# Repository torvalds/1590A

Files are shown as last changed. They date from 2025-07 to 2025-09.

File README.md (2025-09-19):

## Random guitar pedal board designs for 1590A enclosures

> [!NOTE]
> This repository is no longer maintained in favor for [GuitarPedal](https://github.com/torvalds/GuitarPedal).

### Electrical

These are not at all useful, but having done guitar pedal board kit
builds, I decided I should try to make something from scratch.  I don't
actually play guitar, but guitar pedal kits were fun to solder, and that
then turned into "I want to actually understand what they do"...

> [!NOTE]
> I'm not soldering wires together like some kind of animal ---
> thus PCBs designed in KiCad.
>
> And not only don't I solder wires, I like surface-mount
> components.  And not just because some newer stuff isn't
> even available in through-hole form any more.
>
> Everything is designed to be "hand-soldered" --- although
> your definition of hand-soldering may differ from mine. The
> boards are double-sided, but surface mount components are
> only on one side, typically with the other side used only
> for connectors and the like.
>
> I do these without a stencil. It's entirely doable, and I'm
> consciously limiting myself to fairly simple footprints

The design is split up into a "base board" and "effects boards", because
the 1590A is pretty tight.

The base board should work with any of the effect boards, and is purely
about the connectors and stomp switch with true bypass.

The base board does nothing to the signal (apart from the purely
physical switching of the stomp switch), and only does some very basic
reverse polarity protection and has some capacitors for the 9V power
supply.

The effects boards are random "Linus is testing things he doesn't know
anything about".

 - There's a random "Fuzz" board that I may still play around with,
   which just does some random signal clipping with a diode. I'm keeping
   that one around just as a starting point for other potential boards.

 - There's an "Octaver" board that is just a signal rectifier. I started
   out doing those with a op-amp based precision rectification circuit,
   but now it's a dual transistor discrete circuit instead.

   The rectification is objectively worse, but it's not like it made the
   sound any better, and the circuit is much more interesting.

 - There's a plain "clean boost" thing, which should be clean until the
   boosting starts to clip. Which happens pretty quickly since it's a
   pretty aggressive 25dB boost - assuming my simulation matches
   reality, which it might not do.

All of this has been tested and found lacking.  But now my simulation is
much better, and includes some real audio samples.  That didn't make any
of the circuits sound better, but once you realize that any sane modern
guitar pedals are all digital, and that this is just to learn the basics
of transistors etc, that's all good.

### Mechanicals

These are all trivial two-layer boards.  They could be single-sided with
very little routing problem, but that would only complicate things for
no gain.

It's not like I would ever want to even try to etch boards at home any
more, because while I go for "large" components, that's still very
relative.  Etching boards is messy and doing it with the precision
needed for smd is just too painful to be worth it.  See below on
components.

So just use JLCPCB or your favorite other board house.

### Components

Connectors and potentiometers are typically from Tayda Electronics, with
most of the actual common SMD components from kits or from Mouser.

For "random" SMD capacitors and resistors, get one of the kits.  I can
personally heartily recommend the Guanruixin kits from Amazon: there are
0805 and 1206 kits of both capacitors and resistors, and I love the
packaging and labeling.  Very good for organizing at a hobbyist level.

The AideTek kits are good too, but the Guanruixin ones are really
compact for those "get all the values just in case" situations.

Then just go to Mouser or Digikey and buy cut tape for the values you
use more of.  You'll run out of the common resistors in the kits, but
they are still worth having for the less usual ones and just for the
organizing.

And things that are just a bit more specialized - like the the C0G caps
in higher capacitances - you won't find in the kits.

Also, while I'm doing discrete components, I still consider "dual
diodes" etc to be discrete.  In fact I much prefer those for things like
diodes and transistors when possible (and if you want matched pairs
obviously make those a requirement - I realize some people do the manual
matching, but that's not for me).

I've picked SOT-23-6 packages over SOT-363 or SOT-563 because I find
that my limit for enjoying the soldering is at about the 1mm pin pitch.
The 0.65mm or 0.5mm pitch stuff ends up being just annoying.

The resistors are all 0805 size, and capacitors are all over the place:
smaller capacitors in the pF or nF range are 0805, bigger ones are 1206,
and I ended up with 0.1uF C0G in 0704 because it was a common cap choice
for both signal re-biasing and for op-amp bypassing, and doing 1206 was
actually taking up noticeable amounts of board space in some cases.

Electro-mechanical:

 - Tayda A-6976: 1/4" thread lock panel mount mono jack CK635008

 - Tayda A-1848 etc: ALPHA 9mm PCB-mount potentiometers

 - Tayda A-4191: ALPHA 3PDT latching stomp switch.

 - Tayda A-3670 etc: 1M series mini toggle switches and the sub-mini 2M
   series for the side switch.

 - Wuerth 694106301002 9V DC power jack

 - Hammond 1590A enclosure. There are drill patterns that work here:
   ["Tayda drill patterns"](/Tayda/Enclosure-drill-holes)

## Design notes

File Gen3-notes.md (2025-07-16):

Lessons learnt from Gen 1/2:

### Power rails

I started out with various base boards that generally generated negative
power rails, because it felt like the RightThing(tm).  Then Gen2 ended
up just using a virtual ground at 4.5V anyway because anything else was
unnecessarily complex.

But that caused issues too, and when I went all old-school and decided
that even op-amps were too fancy, and I actually wanted to regress to
just entirely discrete components, even the 4.5V virtual ground was just
a distraction.

The simplest discrete boards just don't need it or want it, and even
when they do a reference voltage they don't necessarily pick the
mid-point of the supply.

So the gen3 base board is entirely passive, with no signal buffering or
any re-biasing.  So all the base board does is the stomp switch bypass,
and some very basic power supply sanity (a high-side P-MOSFET for
reverse polarity protection and some capacitors for power supply
stability).

### 1590A enclosure fit

This is a solved problem.  Gen1 was borderline and was playing with
power connectors etc, gen2 tweaked some of the positioning, but I think
gen3 is "done".

The internal inter-board connector did change in gen3, because it's now
simpler with a minimal 4-pin header (just GND / 9V / In / Out) and more
out of the way.  But that didn't affect the enclosure, just the board
pairings.

### Circuits

The lesson from Gen 1/2 has mostly been that I don't actually care about
how things sound, and what I like is the tinkering, and trying to
(still) understand the circuits.

So laying out and soldering the boards is still fun, but using op-amps
to buffer a signal has become "just do it with a transistor".

Because while op-amps are clearly simpler and better to technology to
use, they kind of miss the point of "let's understand what's going on"
by just adding that whole abstraction layer.

So the circuits have regressed to being even simpler and more pointless.

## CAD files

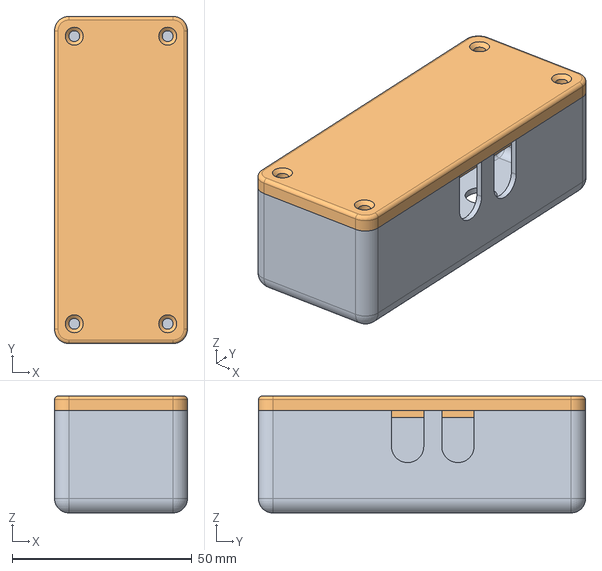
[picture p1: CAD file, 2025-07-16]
Models/enclosure_1590A.FCStd
37.0 x 91.0 x 32.5 mm

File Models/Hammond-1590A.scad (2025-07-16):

// Hammond 1590A enclosure
// Three-pot version with stomp switch and LED
$fn = 100;

// Knob definitions
no_knob = [];
one_knob = [[0,24]];
three_knob = [[-8, 32], [8, 32], [0,16]];
four_knob = [[-8, 32], [8, 32], [-8,16], [8,16]];

// Jack definitions
normal = [[0,-18], [-40,-4]];
splitter = [[0,-18], [-40,-4], [-40,10]];
joiner = [[0,-18], [-40,-4], [0,10]];

// Switch definitions
no_switch = [];
one_switch = [[12,-34]];

// This sets up the configuration
knob_positions = one_knob;
jack_positions = splitter;
switch_positions = no_switch;

screw_positions = [[-14.25,-41.3], [-14.25,41.3], [14.25,-41.3], [14.25,41.3]];

// Do the nice rounded corners and a slight
// taper on the exterior. We'll cut the bottom
// off as part of the cutouts, so don't worry
// about the part going under the XY plane
//
// Bottom: 40.0mm wide, 94.5mm tall
// Top:    38.5mm wide, 92.6mm tall
// 28.5mm high
module exterior()
{
    minkowski() {
        linear_extrude(height = 23.5, scale=[0.9625,0.98]) {
            square([30, 84.5], center=true);
        }
        sphere(r=5);
    }
}

// Same square as the exterior, but the minkowski circle
// is 3mm vs the 5mm sphere.  So basically 2mm walls
module bottom()
{
    minkowski() {
        square([30, 84.5], center=true);
        circle(r=3);
    }
}

// Screw pillar base
module screw_pillar_2d()
{
    for (i = [-1:2:1]) {
        for (j = [-1:2:1]) {
            translate([i*14.25, j*41.3]) {
                hull() {
                    circle(d=5);
                    translate([i*2.5, 0])
                        square(5, center=true);
                    translate([0, j*2.5])
                        square(5, center=true);
                }
            }
        }
    }
}

module screw_holes()
{
    for (pos = screw_positions)
        translate(pos) {
            cylinder(h=14, d=2.9);
            cylinder(h=5, r1=4, r2=1.5);
        }
}

// The bottom extruded up, but with the
// screw pillars removed
module interior_space()
{
    difference() {
        linear_extrude(height=26.5, scale=0.98)
            bottom();
        linear_extrude(height=26.5)
            screw_pillar_2d();
    }
}

// This is the interior that gets removed
module interior()
{
    linear_extrude(height=4)
        bottom();

    interior_space();
    screw_holes();
}

module knob_cutout(pos)
{
    translate(pos)
        cylinder(h=40, d=7.7);
}

module knobs()
{
    for (pos = knob_positions)
        knob_cutout(pos);
}

module jack_cutout(pos)
{
    translate(pos) {
        rotate(90, [0,1,0]) {
            translate([-10,0])
                cylinder(h=40, d=9);
            translate([0,0,20])
                cube([20,9,40], center=true);
        }
    }
}

module audio_jacks()
{
    for (pos = jack_positions)
        jack_cutout(pos);
}

// 9.5mm wide, 14mm high
module dc_jack()
{
    translate([0,45])
        cube([9.5,30,28], center=true);
}

// Stomp switch and hole for LED
module stomp_switch()
{
    translate([0,-34])
        cylinder(h=40, d=13);
    translate([-12,-34])
        cylinder(h=40, d=6);
    for (pos = switch_positions)
        translate(pos)
            cylinder(h=40, d=6);
}

module cut()
{
    interior();
    knobs();
    audio_jacks();
    dc_jack();
    stomp_switch();

    translate([0,0,-5])
        cube([100,100,10], center=true);
}


// Main body
difference() {
    exterior();
    cut();
}

// The lid is the rounded exterior, we're just cutting off
// the top instead of the bottom and then working on that.
module lid_cut()
{
    translate([0,0,20])
        cube([50,100,40], center=true);
    translate([0,0,-2.5])
        linear_extrude(height=3)
            bottom();
}

module lid()
{
    difference() {
        exterior();
        lid_cut();
    }

    // Add corner screw pillars
    // Reinforce around the screw heads
    translate([0,0,-2.5]) {
        linear_extrude(height=5) {
            intersection() {
                screw_pillar_2d();
                bottom();
            }
        }

        for (pos = screw_positions)
            translate(pos)
                cylinder(h=5,d1=10,d2=5);
    }
}

translate([60, 0, 5]) {
    difference() {
        lid();
        translate([0,0,-5])
            screw_holes();
    }
}

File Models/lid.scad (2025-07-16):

$fn=50;

// Knob definitions
no_knob = [];
one_knob = [[0,24]];
three_knob = [[-8, 32], [8, 32], [0,16]];
four_knob = [[-8, 32], [8, 32], [-8,16], [8,16]];

// Jack definitions
normal = [[0,-18], [-40,-4]];
splitter = [[0,-18], [-40,-4], [-40,10]];
joiner = [[0,-18], [-40,-4], [0,10]];

// Switch definitions
no_switch = [];
one_switch = [[12,-34]];

// This sets up the configuration
knob_positions = three_knob;
jack_positions = normal;
switch_positions = no_switch;

screw_positions = [[-15,-42.25], [-15,42.25], [15,-42.25], [15,42.25]];

module cutouts()
{
	translate([20,-25])
		square([7,5], true);
	translate([-20,-25])
		square([7,5], true);
	translate([20,39])
		square([7,5], true);
	translate([-20,39])
		square([7,5], true);
}

module exterior()
{
	difference() {
		minkowski() {
		        square([30, 84.5], center=true);
        		circle(r=5);
		};
		cutouts();
	}
}

// Same square as the exterior, but the minkowski circle
// is 3mm vs the 5mm sphere.  So basically 2mm walls
module interior()
{
	minkowski() {
		square([30, 84.5], center=true);
		circle(r=3);
	}
}

module bottom()
{
	difference() {
		linear_extrude(height=6)
			exterior();
		translate([0,0,2])
			linear_extrude(height=5)
				interior();
	}
	translate([-10,20])
		cylinder(h=3.8, r=2);
	translate([10,20])
		cylinder(h=3.8, r=2);
	// Walls
	translate([18,20])
		linear_extrude(height=11.5)
			square([4,20],true);
	translate([-18,20])
		linear_extrude(height=11.5)
			square([4,20],true);
	translate([18,-33])
		linear_extrude(height=11.5)
			square([4,10],true);
	translate([-18,-33])
		linear_extrude(height=11.5)
			square([4,10],true);		
	translate([0,-(84.5/2 + 5 - 2)])
		linear_extrude(height=11.5)
			square([20,4],true);
}

module holes()
{
	translate([0,-34])
		cube([21,18,10], true);
	translate([12,-34,-5])
		cylinder(h=40, d=10);
	for (pos = knob_positions) {
		translate(pos)
			translate([0,-2,0])
				cube([11,13,10], true);
	}
}

module top()
{
	difference() {
		bottom();
		holes();
	}
	translate([-10,-20])
		cylinder(h=3.8, r=2);
	translate([10,-20])
		cylinder(h=3.8, r=2);
}

bottom();
translate([-10,2])
	cylinder(h=3.8, r=2);
translate([10,2])
	cylinder(h=3.8, r=2);
translate([45,0])
	top();
for (pos = screw_positions)
	translate(pos)
		cylinder(h=21, d=6);

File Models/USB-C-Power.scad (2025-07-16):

// Simple enclosure for the USB-C power board
//
// Board dimensions:
//    80 x 30mm with 5mm corner radius
//
// DC jacks centered on front panel at X -30, -10, +10, and +30mm
// USB C receptable on back panel at +20mm
//
// board: 1.6mm thick with 2mm high components (3.4mm if choke on back)
// so let's say 5mm undercut
//
// Top of board: DC jacks 11mm high, but caps up to 12.5mm, go for
// 15mm space above: 20mm total cavity height.

$fn = 100;

// Corner locations
corners = [[-40,-15],[-40,15],[40,-15],[40,15]];

// 3mm hole board locations
holes = [[-35,+10], [+35,+10], [-20,-7.5], [+20,-7.5]];

module board_2d()
{
    minkowski() {
        square([80,30], center=true);
        circle(r=1);
    }
}

// 2mm walls around the board cutout
module exterior()
{
    minkowski() {
        linear_extrude(height=20)
            board_2d();
        sphere(r=2);
    }
}

// 9mm wide, 11mm high with 0.5mm for slop
// Translate up 10.75mm: 5mm undercut + 5.75mm for half the height
module dc_jacks()
{
    for (x = [-30:20:30])
        translate([x,-15,10.75])
            cube([9.5,15,11.5], center=true);
}

// USB-C cable cutout:
//    Plug end dimensions:   8.35mm x 2.56mm
//    Cable end dimensions: 12.35mm x 6.5mm max
// So basically cable is 2mm on each side of the plug.
//
// Centered at 5mm undercut + 1.6mm up from the board
module usbc_jack()
{
    translate([20,10,6.6])
        minkowski() {
            cube([8.35,20,2.56], center=true);
            sphere(d=3.8);
        }
}

// The capacitors in between the DC jacks can be high
// and might need a cutout because of how we support
// the DC jacks above.
module capacitors()
{
    translate([0,-4,5])
        cylinder(h=12.5,d=8);
    translate([0,-11,5])
        cylinder(h=12.5,d=8);
}

module mounting_pin(loc)
{
    translate(loc) {
        cylinder(h=3.4, d1=12, d2=8);
        translate([0,0,5])
            cylinder(h=15, d=8);
    }
}

module screw()
{
    // 0: 3 5: 2.9 10: 2.8 15:2.7
    cylinder(h=15, d1=3, d2=2.7);
    translate([0,0,-2])
        cylinder(h=7, d1=8, d2=3);
}

module corner_clips()
{
    translate([0,0,5])
    for (loc = corners)
        translate(loc)
            cylinder(h=15,r=3);
    translate([0,0,2])
        linear_extrude(height=3)
            intersection() {
                for (loc = corners)
                    translate(loc)
                        circle(2);
                board_2d();
            }
}

module cutout()
{
    // Extrude the board cutout, but not above the DC jacks.
    // We'll separately cut out the DC jacks to keep them
    // captured for easy soldering inserted in the box.
    // Also, we don't cut out the mounting pins around holes.
    difference() {
        linear_extrude(height=20)
            board_2d();
        translate([0,-15,20])
            cube([80,15,10], center=true);
	for (loc = holes)
            mounting_pin(loc);
    }
    translate([0,0,3.4])
        linear_extrude(height=1.6)
            board_2d();
    dc_jacks();
    usbc_jack();
    capacitors();

    // Add screw holes
    for (pos = holes)
        translate(pos)
            screw();
}

module box()
{
    difference() {
        exterior();
        cutout();
    }
}

// Now do it twice for the upper and lower parts, cut off at 5mm
// The box itself
difference() {
    box();
    cube([100,100,10],center=true);
}

corner_clips();

// Lid
translate([0, -45, 0]) {
    difference() {
        box();
        translate([0,0,35])
            cube([100,100,60],center=true);
    }
}

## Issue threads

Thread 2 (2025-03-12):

Let's bring this project together in FreeCAD

alekssadowski95, 2025-03-12:
Create CAD assembly from pcbs and a 3D-printable enclosure in FreeCAD.

Tell me which boards you would like to be combined in one enclosure.

alekssadowski95, 2025-03-13:
I will keep my answer short on purpose, so that we can advance this project.

How are the pcs mounted inside of the Hammond 1590A enclosure? Do you screw them onto the lid or enclosure body also using a non-conductive spacer such as a PTFE-tube, or are the pcbs just hanging by their connector?

Because I don't know anything about guitarboards, just FreeCAD, it would be best if you could provide a list of all pcs on an examplary configuration contained in one enclosure.

e.g. "Sample configuration":
- [Octaver board](https://github.com/torvalds/1590A/tree/main/Effects/Rectifier)
- [DC jack board with an LT1945](https://github.com/torvalds/1590A/tree/main/DC-Jack/LT1945/)
- ...

torvalds, 2025-03-14:
So it really would be exactly that. Just two boards attached together: the octaver (called "Rectifier" because that's the key circuit that makes it different from the Baxandall board) and the LT1945 base board.

I'm also exploring using a third PCB as a faceplate.:

  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

because it looked like a fun idea. Either with a 3d-printed box or even just a resin pour.

Note that guitar pedal on/off switches are called "Stomp Switches" for a reason. You use your foot to turn the pedal effect on and off. Not gently. So the sturdy aluminum enclosure is traditional.

alekssadowski95, 2025-03-14:
Sounds great! I will come back to you soon with some results. We will then have a more concrete basis for discussion. Because I am working on crash simulations using open-source software right now, we can even simulate the stomping and its effects on the 3D-printed plastic enclosure and make sure it withstands its intended use case, before even printing it out to test.

alekssadowski95, 2025-04-14:
Hello Linus, sorry for the late reply. I have given the project of designing an enclosure to one of our interns. Here is how it looks like up until now. He has used the dimensions from the Hammond 1590A enclosure.

Just to be clear, are both pcbs within one enclosure or are they separate? Here one is screwed into the lid, while the other one is screwed into the bottom.

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

torvalds, 2025-04-14:
Your connectors are the wrong way around, but the enclosure sizing looks spot on.

I think the easiest way to explain the layout is to just add a few pictures of the project.

1: the back of the base board:

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

2: the top of the base board:

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

3: the back of the effects board:

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

4: the top of the effects board:

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

5: connected together (from the side, so you see the pin header/connectors):

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

6: Connected together (more obvious "this is what the end result is" angle):

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

7: in an actual 1590A enclosure (but without knobs, my bad):

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

torvalds, 2025-04-14:
That's the boost board, which is pretty much the simplest of the effects, but has all the knobs and switches. But you can see that the actual _circuit_ is trivial: it's just a op-amp as a boost amplifier, with the switch selecting two different diode clipping options (or no clipping at all for a clean sound).

Note that the location of the stomp switch and audio jacks have changed since the first original version, and the LED got moved over to the side to make room on the effects board. This particular effects board obviously has tons of space and didn't need that, but some of the things I was playing with had more circuitry, and the potentiometers and the stomp switch take up a lot of board space, so...

torvalds, 2025-06-05:
Closing this issue - I've committed some enclosure CAD files.

Not using FreeCAD, but OpenSCAD instead, but they do print out ok. Certainly room for improvement, but usable if you don't want to use a real 1590A and drill holes (or pay Tayda to do so).

alekssadowski95, 2025-06-05:
I will do a PR with the FreeCAD files

Closed 2025-06-05.

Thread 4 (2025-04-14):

Tremolo doubling as a metronome

torvalds, 2025-04-14:
Just putting this here to remind me to look at it.

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

that's the difference between simulation and reality. Or possibly just me using the wrong model for the MOSFET.

The tremolo has a ticking sound as the MOSFET closes due to that signal spike. Other than that it actually seems to work well and sounds ok, it just does a bad impression of a metronome too.

Twofer!

torvalds, 2025-04-14:
Bah. I can actually see it in simulation when I went looking for it, I just hadn't looked for it, and the other signals I was tracking hid it.

I can hide the pop with a low-pass filter, I guess, but there's probably some "real solution" that I just don't know about.

Oh, the joys of not knowing what I'm doing...

supervoidcoder, 2025-04-14:
>
> Oh, the joys of not knowing what I'm doing...

Relatable… hah
Everything can double as a metronome if you slow or speed it up enough.
Maybe you can keep it in as a separate part? Like a built in metronome? This is clearly a feature, not a bug

torvalds, 2025-04-14:
Well, once I saw it in simulation, it was easy enough to play around with, and the solution appears to be fairly simple: don't use the harsh square wave as the gate control. Which is easy enough - instead of using the output of the opamp (which does that hard swing rail to rail), I can just take the LFO output from the capacitor voltage instead.

That approximates a triangle wave (as the capacitor charges and discharges), and makes the nasty little spike in the signal go away. At least in simulation.

And while at it, I also fixed the fact that I put the transistor that drives the LED the wrong way around. Oops.

Hey, it's why I do this - learning new things.

gralco, 2025-04-15:
You mentioned that you've got a simulation going. Are you doing this outside of KiCad?

You probably know this, but you can do SPICE simulations inside KiCad which can make it easier to follow along.
https://www.kicad.org/discover/spice/

I can provide some help with this if you need.

torvalds, 2025-04-15:
@gralco I've done some simulations inside of KiCad, but admittedly most of them outside.

I found the kicad error messages (well, I guess ngspice) generally "unhelpful" to put it politely. I did mostly figure it out, but found it off-putting enough that I didn't really get into it.

In the meantime I had done some simple simulations in circuitlab (which has its own set of issues, particularly since I like labeling my nets rather than having tons of wires, and circuitlabs doesn't seem to do that), and rather than add simulation model info to every symbol I add, I mostly just check particular things I want to look into at CL instead.

I'm not particularly careful about the simulations. I started this because I enjoy the tinkering with building these things, not because I'm going to build some great and innovative piece of electronic.

So I'll simulate enough that I think some part of the circuit is in the ballpark, and then I'll send it off to jlcpcb.  It takes a week to get boards back, but I'll have a couple of boards in the pipeline at a time, so I get boards back every three or four days, and then I find some new issue to look at.

Half my issues have been about just getting rid of noise so that I can see my circuit problems clearly. I wasted some time with a bad power supply before realizing that some of the noise wasn't actually my fault. But much more time was wasted on figuring out the right way to actually hook things up so that I can get a clean enough picture that I can see spikes like the one that made me open this issue.

Of course, "wasted" is really the wrong word. This kind of tinkering is very much why I started doing this all.

gralco, 2025-04-15:
@torvalds I understand your pain with the error messages since I just tried simulating your tremolo circuit in KiCad. It seems to be having a hard time with TI's OPA1655 SPICE model in particular. It's being fickle depending on how you set up the time step or the values you pick for your pots' resistances.

I modelled your RV2 pot using two resistors, which add up to 100k together. These "fake" resistors are set to be excluded from the board and BOM so it's like they don't exist (just for simulation).

Anyway, I almost got it working, though the LFO isn't getting into oscillation for some reason. I'm sure it would be a lot more reliable if I used a different model for the opamp.

In your own simulation (and also in your measurement there in your first post), what are you using as your V(IN) signal?

It'd be cool to reproduce what you're seeing in real life in the KiCad+Ngspice simulation.

torvalds, 2025-04-15:
@gralco - I didn't have any issues with modeling the pots: I just picked the built-in spice resistor simulation model and selected a potentiometer. That part was fine.

But yeah, the opamps were a pain and my naive attempt at just importing the TI spice model for the 1656 (and 1655) just failed. I ended up figuring out that the time step error verbiage from ngspice were basically not about any time steps at all, but about entirely unrelated setup issues, but now I forget how I solved them (but I *think* I solved them by just picking some other opamp entirely to simulate - now I can no longer find my simulation circuit).

I also use that MMBD1203 dual diode package on multiple boards because I typically rather solder that than single diodes where I have to care about polarity. And ended up deciding that describing the simulation part was too much effort and didn't find anything native, so instead in simulation I just did it as two separate standard diodes.

So even when I simulated in kicad, I didn't actually end up simulating the *actual* board I was doing, I just did a separate simplified subset of the circuit. Which kind of defeats the purpose, but oh well.

As to the incoming signal, I just typically use a 200mV peak-to-peak sine wave. Typically at 1kHz, although for the tremolo thing (which I only simulated at circuitlab) I did the simulation using a 100Hz V(IN) signal because the frequency doesn't matter and the resulting signal graph just looks better when you need to simulate over a second or two since the LFO is oscillating at just a couple of Hz (so a 1kHz signal would just get very busy).

The real signal on the scope in the picture is from my signal generator.  Also ~200mV peak-to-peak, but set to some random frequency in the audible range.

Just checked: my signal generator is currently set at 210mV PtP at 344.444Hz. and that *probably* matches what is on the picture. Not that there is anything magical about those numbers, I just pick things with the knobs randomly (mainly for some of the other effects boards that have a Baxandall tone circuit, so I go up and down in frequency just to verify that the magnitude of the signal changes appropriately by frequency - but the tremolo board currently doesn't do any tone control, so I wouldn't have done that there).

The ~200mV amplitude is "reasonably typical" for a guitar signal, even if "sine wave" certainly isn't ;)

gralco, 2025-04-15:
I got the simulation working. I had RV1 excluded last time which is why it didn't oscillate.

I'm getting ~10.5Hz with RV1 set to 50k:

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

This is using TI's OPA1655 model.
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
gralco, 2025-04-18:
@torvalds I've been struggling with this for last couple hours and I'm starting to think that we can alter passives' values but not parameters of models (at least maybe not yet). I've tried just about every combo of `alter` and `altermod`, even going as far as to stick in a model of the pot rather than using KiCad's built-in one based on this: https://forum.kicad.info/t/how-to-use-in-kicad-a-model-from-ngspice-manual/52069/3

I don't want to throw in the towel just yet, I feel like I'm probably just doing it wrong, but I'm pretty sure I've exhausted all combos of `alter @potia.XSW1[pos] = <val>`, `altermod @potia.XSW1[pos] = <val>`, `alter XSW1 pos = <val>`, `alter @SW1[position] = <val>`, etc. Using the syntax described in [13.5.3 of the Ngspice manual](https://ngspice.sourceforge.io/docs/ngspice-manual.pdf) with the subckt name, the part's reference designator (shows up as XSW1 in the netlist but I also tried SW1 of course), and both "position" and "pos" for the parameter.

It's driven me crazy because I know it works just fine for passives. I think that's why Holger (Ngspice dev) is suggesting using two resistors to emulate a pot here: https://forum.kicad.info/t/is-it-possible-to-perform-a-simulation-with-parametric-sweep/45178/6

As a temporary workaround you can stick a couple of resistors in your simulation box with net labels that connect them to where SW1 is. Set SW1 as being excluded from the sim and set the simulation-only resistors as being excluded from the BOM and board.

gralco, 2025-04-18:
@torvalds Wow, I keep doing this, I reply that "it doesn't work" and then I get it.

So I didn't mention `alterparam` but I did try this before too, but I did a bit more RTFM and found out that I needed to do `reset` after it.

I took a hatchet to your circuit by deleting D1 and replacing it with a short just to make it super obvious to me which way the SPDT switch was set to:

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

And this is what it yields:

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

Here I'm still using this as `pot.lib`:
```
* code model for potentiometer
.subckt potia ru wp rl params: pos=0.5 Rtot=10Meg
.param pos=0
.param Rtot=10Meg
Apot rl wp ru potmod
.model potmod potentiometer(position={pos} r={Rtot} log=FALSE log_multiplier=1)
.ends
```

Next I'll try to figure out how to KiCad's built-in model for a pot instead (need to figure out its subckt name I think).

gralco, 2025-04-18:
Oh and btw, I'm not sure if this happens for you on KiCad 8.0.9 (which I'm also on after downgrading), but I have to close Eeschema and reopen it whenever I edit the .control script, so be careful you don't get snagged by that.

gralco, 2025-04-18:
I haven't found a subckt name for the built-in potentiometer model, I think it may not have one. Here's the code for it (I noticed they're using `altermod` for the slider, haven't gotten that to work in the .control script): https://gitlab.com/kicad/code/kicad/-/blob/master/eeschema/sim/sim_model_r_pot.cpp

I tried adding a "Sim.Name" parameter and using that, but that did nothing. There's probably some way to use the built-in one, but for now I'll just suggest using the model I shared earlier along with using `alterparam` and `reset`.

torvalds, 2025-04-18:
@gralco - thanks for your work. I ended up being sidetracked by real work and by doing the actual PCB side to send off the new versions for manufacturing. Which hopefully fix the oscillation for good now that I have it in simulation.

Using a custom model for the pot looks like a great solution, even if I think it's odd how little of this kind of basic infrastructure is part of the standard KiCad setup.

Or maybe it's just that I'm doing odd things. But I can't imagine that I'm even remotely the first person to design an old-fashioned analog guitar pedal with KiCad.

I'll leave this issue open for now, but I expect to close it when I get boards back next week (I'm expecting the issue to be fixed, but will wait until I actually see and hear it being fixed).

Thanks again for all your help. The simulation feels invaluable, and I should have done it earlier, but all the nasty small problems I hit ended up just killing my motivation for it.

torvalds, 2025-04-18:
Oh, one last question (I lie, I lie - I'm sure it won't be the last one at all).

While simulating the tremolo circuit, I couldn't make any sense at all of the LED simulation. I wanted to make sure that it actually has current running through it at the right times. And none of the results made any sense at all. So to be safe, I ended up just connecting the LED to the output of the opamp directly, because there the harsh rail-to-rail square wave really doesn't matter, and that 1655 can drive up to something like 100mA of
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

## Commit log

2025-07-16 Random guitar pedal project gen3: Discrete Components
    This is a reset of the 1590A pedal project, because unlike any sane
    project, this one goes backwards.
    Instead of making fancier and more complex pedals, this is the "Benjamin
    Button" of guitar pedal projects and ages in reverse. As the project
    ages, it goes back in time and the circuits become more primitive.
    So in Gen1, I was exploring power rails and packaging, with all the
    signal paths being basically op-amp circuits. In Gen2, I had largely
    standardized on a virtual ground at 4.5V.
    And then I was exploring long-tailed pairs and the like, and as I
    started to feel like I understood some of the transistor circuits
    better, I decided t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
    [Boost.kicad_pcb, Boost.kicad_sch, Fuzzy.kicad_pcb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]
2025-07-17 Fix up some initial Gen3 commit issues
    Most notably, when I reset the history I effectively also screwed up the
    credit for the FreeCAD enclosure, which isn't by yours truly. So add an
    explicit note on the history of that file with a pointer to the commit
    in the history (see commit b5d59be: "Added FreeCAD native file of 1590A
    enclosure").
    Also fix up some paths for simulation workbooks that didn't get properly
    updated when I renamed things by hand to remove the "Discrete" part of
    the names.
    And minor typo fix.
    [Octaver.kicad_sch]
2025-07-18 Clarify and tweak the clean boost circuit a bit
    This adds more information about the actual transistor biasing choices,
    and tweaks the details a bit more. More importantly, this actually
    documents the thing, with explanations for the particular choice of
    resistors and voltage biases.
    The maximum amplification is slightly less, but it should be pretty
    clean, with a 15dB amplification of up to a 0.9V PtP signal (so turning
    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
    [Boost.kicad_pcb, Boost.kicad_sch]
2025-07-18 Add a three-way Bright / Clean / Blunt toggle to the boost circuit
    Ok, I admit it: this was another thing mainly introduced because my
    standard enclosure has three holes for pots and switches.
    But it's also because "clean" is just too boring on an oscilloscope if
    it actually ends up being as clean as it looks in simulation.
    So the switch just adds options for bypassing the emitter resistor for
    some not-so-clean boosts, where it's easier to get clipping to the point
    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
    [Boost.kicad_pcb, Boost.kicad_sch]
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2025-07-20 Add MMBF5103 JFET to my symbol library
    So I've been using the J201 in my JFET input buffers, because I got that
    JFET as apparently being a "traditional" JFET in guitar pedals.
    But I also added the MMBF5103 to my component library since it seemed to
    be a rather better JFET in many ways, with a reasonable V_{GSOFF} range
    (-1.2V .. -2.7V) and I_{DSS} range (10mA .. 40mA).
    In contrast, the V_{GSOFF} of the J201 is officially -0.3V .. -1.5V,
    which is kind of tight for the simple "self-bias to ground" approach.
    Now, I measured one of mine to be pretty much right in the middle at
    -0.8V, and that matches what the spice file says, so at a guess with
    modern manufacturing it's probably much tighter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
2025-07-20 Replace the J201 in the boost circtui with a MMBF5103
    This is just a drop-in replacement, no other circuit changes.
    It does simulate with a higher DC source voltage, and a much bigger
    input voltage swing range. But the J201 was fine with normal guitar
    pickup voltages, so it's not like any of that should matter.
    [Boost.kicad_sch]
2025-07-20 Update the Octaver circuit for MMBF5103 use
    This not just switching the J201 into a MMBF5103, because when I did
    that to verify that it's just a drop-in replacement, the simulation got
    very unhappy indeed instead of saying "yup, same thing".
    It looks like the extra current going through the 5103 ends up then
    going through the subsequent BJT rectification stage, and the two stages
    interact in bad ways causing oscillation on the phase-shifted signal.
    That is easy enough to fix with just resistors between the stages. But
    I am also unhappy with the simulation voltages because the simulation
    isn't seeing the capacitor on the base board, so I'll handle that
    separately.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
    [Octaver.kicad_sch]
2025-07-20 Update the Octaver circuit more, improve simulation
    When I was trying to look up JFET phase splitter cicuits, I came up
    suspiciously empty. Adding the resistors between the phase splitter and
    the rectification stage did fix things in simulation, but it all makes
    me think somebody knows more than I do about this.
    So since I wanted some amplification anyway, I put another BJT stage
    there for the phase splitting, and one in the output stage for
    amplification.
    And I added the base board to the simulation, so that the whole input
    signal rebiasing actually shows up for real. With the DC-blocking
    capacitor no longer on the effects board, the simulation ended up seeing
    the signal input as a powe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
    [Octaver.kicad_sch]
2025-07-22 More octaver circuit impedance tweaking
    I decided that the JFET phase splitter is the right way to go after all,
    and that I just need to make sure the output impedance is low enough for
    the following circuit. Smaller transistors, more current, stiffer
    signals.
    But "more current" in this case is still in the "a couple of mA" range,
    and this isn't battery-operated, so to quote Alfred E Neuman: "What, me
    worry?"
    I'm not particularly happy with that output side, and I'll probably
    continue to play with this to get a better feel for the whole input and
    output impedance of the different transistor circuits. But maybe it's
    time to make another test pcb just to see if this works in reality at
    all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
    [Octaver.kicad_pcb, Octaver.kicad_sch]
2025-07-23 Fix up my BAT41ZFILM symbol
    I had the simulation pins the wrong way arund, which caused no end of
    annoyances and confusion.
    And turn the graphical representation around too, anode to the left,
    cathode to the right. That's the normal way to show diodes.
2025-07-24 Try to do a JFET compressor circuit. Again.
    No, really. I don't seem to learn from past mistakes. I keep thinking
    that I can do a JFET compressor circuit, and they all fail miserably.
    This one simulates in good ways for one particular amplitude-modulated
    test signal.
    Of course, one major problem with JFET's is that the physical
    characteristics are all over the map, and this does *not* have any
    tuning for that. So reality will be very very different.
    I doubt it works this time either, and I do need to have some way to
    tune the JFETBIAS voltage. But hey, it looks fine in simulation, and it
    finally uses the rectification circuit for something that might not be
    horrible noise.
    Who am I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
    [Compressor.kicad_sch]
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2025-07-24 Add triangle wave for compressor testing
    Because of how this odd "JFET as a voltage-controlled resistor in
    parallel with a capacitor" circuit works, the whole ngspice AC signal
    analysis doesn't work for this at all. Which limits me to just the
    transient analysis.
    So to do a poor-man's frequency sweep kind of thing, by using a 125Hz
    triangle wave as an input and seeing how it distorts.
    Does that show distortion? It sure does.
    The thinking is that it's kind of a capacitor version of a resistive
    T-network, with the reactance of the capacitors all frequency-dependent
    in the same way (so scaling up and down together).
    But then the JFET ends up being a non-frequency-dependent resistance
    pullin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
    [Compressor.kicad_sch]
2025-07-24 Compressor: Use bigger capacitors in signal path
    This just changes the 0.1uF caps in the signal path to 0.47uF ones.
    That doesn't fix all ills, but it should pass lower frequency signals a
    bit better.
    This does make them 1206 footprints, and maybe the board will be a bit
    tight. I'm starting to look at the PCB next.
    [Compressor.kicad_pcb, Compressor.kicad_sch]
2025-07-24 Compressor: do a first PCB layout
    I thought this was going to be tighter than it was, so I started laying
    out things unnecessarily densely. Also, the lower left section (the
    final signal amplification) would actually have been better off moved up
    closer to the volume pot, but by the time I realized that I had tons of
    space and shouldn't have squeezed things down there, it was mostly done
    and I just didn't bother to change it to make a nicer layout.
    I just want to know if this works at all, or if the simulation is just
    being unreasonably optimistic.
    If it actually works, I'll at a minimum want some kind of "it's now
    starting to compress" LED or similar. And I'd want to do it as a
    feedback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
    [Compressor.kicad_pcb]
2025-07-25 Add my BAT54S as a symbol
    Yeah, KiCad already has a BAT52S that looks about right, but it says
    it's a SOT-323 in the name even though the footprint is actually the
    correct one (SOT-23-3). The two are not the same at all. Don't you
    love SMD name confusion?
    Perhaps more importantly, this one has the simulation data associated
    with it so that I don't need to look it up.
2025-07-25 Compressor: re-do with feedback loop and a whole new approach
    So as mentioned earlier I started looking into using a feedback loop
    rather than base the compression purely on the input signal amplitude,
    and as I was working on that, I realized that I had been thinking of the
    JFET signal attenuation entirely the wrong way the whole time.
    My confusion actually started way back with the old tremolo circuit that
    I had so many problems with, and it all stems from just thinking that I
    should use the JFET as a variable resistor to pull the signal down to
    ground.
    Yeah, yeah, that makes conceptual sense, but it's actually not the right
    way to go about this all, because I realized that I was just mak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
    [Compressor.kicad_sch]
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2025-07-27 More compressor updates: add pots for attack / decay tuning etc
    Lots of minor changes, but the user-visible one is that there is
    (limited) control of the attack and delay now. But the whole compressor
    level setup has also changed, and the signal amplification is done a bit
    differently too using the NPN/PNP pair in the NMB2227A.
    Can you say "trying out random things"? I knew you could.
    Let's get this manufactured and see if it actually works, since I won't
    have time to mess with the design any more as the merge window opens and
    my travel season starts.
    [Compressor.kicad_pcb, Compressor.kicad_sch]
2025-07-27 Gaah - Fix stupid PNP direction mistake
    I've done this *so* many times: I turn the PNP around by rotating it
    like it's some random resistor, not my mirroring it around the Y-axis,
    and I end up with the transistor the wrong way around without noticing
    it.
    And I did it *again*.
    It didn't actually seem to matter for simulation, because this whole
    "use a series pair" was just for the lulz and there wasn't any big
    current or voltage gain expected. And so the single NPN was perfectly
    happy to drive it all.
    But it's still very wrong indeed.
    This just fixes the direction of the transistor, but I'll go look closer
    if it had some unfortunate effect on the rest of my flawed results.
    Signed-off-by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
    [Compressor.kicad_pcb, Compressor.kicad_sch]
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2025-08-12 Plain base: noise from kicad version update
    Nothing changed, just output from loading and saving the files with a
    slightly newer kicad version.
    [Plain.kicad_pcb]
2025-08-12 Octaver: file noise due to kicad version update
    This also works around a bug in this pre-release of kicad: four wires in
    the schematic that meet in the middle have their connections removed, so
    you end up with two crossing wires rather than four connecting wires.
    Quite annoying, but for now the workaround seems to be to just never
    have a join of four wires coming together, but do two three-wire
    connections.
    I'm sure it will get fixed soon in Kicad, but I have been tracking
    random daily source versions and rather than downgrade to a working
    version, I'm working around this misfeature.
    [Octaver.kicad_pcb, Octaver.kicad_sch]
2025-08-13 Compressor: More kicad file noise
    This just re-annotates the schematic and undoes the workaround for the
    kicad bug with crossed wires that has now been fixed.
    Link: https://gitlab.com/kicad/code/kicad/-/issues/21480
    [Compressor.kicad_pcb, Compressor.kicad_sch]
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2025-08-15 Update compressor PCB layout too
    This does the new trial matches JFET thing as a board layout too. I'm
    really not convinced this was worth it, and the routing and layout are a
    bit of a mess, but it's all part of the whole learnign experience, and I
    do want to see if the self-biasing thing actually works in real life or
    it just happens to look ok in simulation with the particular simulation
    values.
    .. and the usual noise from KiCad inexplicably changing randon things
    when looking at files.
    [Compressor.kicad_pcb, Compressor.kicad_sch, Plain.kicad_pcb]
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2025-08-17 Add the beginnings of a dubious buffered base board
    As part of looking at what I should try to use my MOSFETs for, I decided
    I should finally look at a soft-switch buffered base board.
    This is not it, but it starts with a very dubious push-on push-off
    MOSFET circuit. I doubt it really works, even if it simulates
    beautifully. But I don't simulate any debounce issues etc, although I
    don't see why it wouldn't deal with that too.
    All the real push-on push-off circuits I've seen are more complex than
    this, which is the main reason why I doubt that my simple circuit really
    works. It's a bit *too* simple. Everybody uses some flip-flop and/or
    schmitt trigger or other fancier things.
    But hey,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
    [Buffered.kicad_pcb, Buffered.kicad_sch]
2025-08-17 Wire the soft-switch up to actually switch signal and LED
    Surprisingly, this actually seems to work fine. In simulation only, of
    course.
    And not surprisingly, according to the same simulation, it has an
    impressively horrible pop at switching time. This very much reminds me
    of the broken "Tremolo doubling as a metronome" thing, which was due to
    the exact same thing: very harsh and sudden driving of the JFET gate.
    It's made worse by the MOSFET switching having the same thing. Big
    voltage spike when turning off, presumably due to capacitive parasitics
    or whatever.
    Possibly helped by adding a resistor at the gate or something, but
    unlike the tremolo, the switching event is rare. So right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
    [Buffered.kicad_pcb, Buffered.kicad_sch]
2025-08-17 Buffered base: add RF filter after JFET switches
    It turns out that getting rid of the switching pop seems to be as simple
    as that.
    Maybe time to do PCB layout and see if reality matches simulation?
    I do think I should do the buffer that this doesn't do despite the name.
    That was the intent, but then it worked so well without it.. An op-amp
    would be the sane thing to do, but since I've been on a "discrete
    components" tear, I suspect I'd just do a JFET voltage follower.
    But then I feel like I should make up for the inevitable signal loss.
    Or use a common source thing that does a phase reversal? That seems
    wrong too. Perhaps do another dual JFET for a common source both at
    input and output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
    [Buffered.kicad_sch]
2025-08-18 Split the buffered base over multiple schematic pages, do PCB layout
    So this thing is still mis-named, in that it doesn't actually buffer the
    signal at all, it only does the transistor soft-switching. But I _will_
    add buffering at some point, it's just not the interesting part of this
    all, since I've done that part before.
    But because I wrote explanations for the push-on / push-off circuit, and
    because I split things up into small parts, the schematic was getting
    pretty crowded. So I decided to split up the actually interesting part
    of the schematic - the switching side - onto a schematic page of its
    own.
    And while doing that, I moved the simulation infrastructure to its own
    page too.
    T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
    [Buffered.kicad_pcb, Buffered.kicad_sch, Switch.kicad_sch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]
2025-08-19 Add LT3462A symbol
    I'm going to experiment with a negative power rail one more time, and in
    the LT3462A I found a DC/DC converter that looks a lot more pleasant
    than the ones I've tried before.
    Not only is it a nice TSOT-23-6 footprint, but it has an integrated
    schottky diode so it's easy to use. And it's a fixed frequency dual
    inductor inverter design, so it should be reasonably quiet in the audio
    frequency.
    I'm not planning to bother with LDOs to clean up the power rails,
    because the reason for the power rail would be the op-amp for buffering,
    and the PSRR of any quality opamp should make it all irrelevant.
    I dunno. Every time I've tried this, it's just been noise hell, so this
    is pro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
2025-08-20 Buffered base: use negative rail for JFET switching
    This _still_ doesn't do any actual buffering, but with the negative
    rail, we now no longer need to rebase the signals to some mid-point
    voltage, and we can just leave the signals ground-references and use the
    negative rail for switching.
    That streamlines the signal path, and will make it easier to just insert
    an opamp or two in there too. But I remain more interested in getting
    the switching side sorted out properly, so that's the primary goal here.
    This tweaks the push-on push-off circuit a bit too, since taht one now
    needs to switch between positive and negative voltages rather than VIN
    and ground.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
    [Buffered.kicad_pcb, Buffered.kicad_sch, Switch.kicad_sch]
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2025-08-28 Add AP2202-ADJ LDO symbol to my parts library
    I don't think I'll actually end up using this, because the negative
    voltage generation just ends up being more pain than it is worth, but I
    think I'll do one last test-run of things with a nice linear voltage
    regulator to make that positive rail more solid.
    I've been here before: I'd like to have a dual rail voltage for so many
    reasons, but the end result is just rather noisy. Not just on the
    actual negative rail, but on the incoming positive rail too. The dual
    inductor thing does seem less noisy than most, but it still requires
    just more work.
    Even the traditional charge pump wasn't great.
    It's all fixable, but the fixes tend to end up maki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
2025-09-03 Create a pedal design based on the Electrosmith Daisy Seed platform
    This tries to make the pedal actually useful by making the audio side
    use the Daisy Seed from Electrosmith [1]
    I've had the board for the last six months, but up until now didn't feel
    ready to use it.
    I even built the Hothouse pedal kit around it, and exchanged some emails
    with both Andrew Ikenberry (Electrosmith) and Ricky Sheaves (of Hothouse
    pedal from Cleveland Music Co), but never even flashed it up to test.
    But now that I'm getting bored with trying variations of the basic
    analog base board, let's switch things up a bit and do a base board for
    the Daisy Seed instead.
    Because assuming I don't mess anything up, it's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
    [DaisySeed.kicad_pcb, DaisySeed.kicad_sch, sim.kicad_sch]
2025-09-04 Downgrade Daisy Seed boards to kicad v9.0
    Since I don't do audio signal simulation with the Daisy Seed boards,
    let's try to downcovert to the standard kicad version to make it easier
    to use without having to have a self-compiled version.
    Kicad doesn't make this particularly easy, I'm afraid. Let's hope this
    didn't do anything bad. It still simulates, and looks superficially ok.
    [DaisySeed.kicad_pcb, DaisySeed.kicad_sch, sim.kicad_sch]
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2025-09-04 Finish down-converting a couple of the old boards to KiCad 9.0
    This just does the "load into kicad, fix up, save" dance for the plain
    base board. Also do the Octaver and compressor effects boards to check.
    This finishes the conversion back to KiCad 9.0.
    I think I'll just leave the other boards alone: I think I'm done with
    them anyway, and we'll just leave them in that zombie state for
    posterity. I just wanted to check that the scripted conversion seems to
    mostly work for these things.
    You do want to do some manual fixups for this stage: removing the use of
    real sound files from simulation (since it doesn't exist in released
    kicad/ngspice versions), updating symbols and footprints from t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
    [Compressor.kicad_pcb, Compressor.kicad_sch, Octaver.kicad_pcb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]
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2025-09-07 Try attaching the Daisy Seed directly on the base board
    Ok, so to fit this thing, I needed to play some games, and also get rid
    of the third potentiometer.
    So now it only has two pots, and the Daisy Seed needs to be the
    unsoldered kind, where you solder low-profile pin headers to the "wrong"
    side of the board.
    IOW, the Daisy Seed gets mounted upside down on the top of the base
    board, and then it kind of fits.
    I say "kind of", because this is all without a stomp switch. I haven't
    decided on what I want to do about that. The switch connector is just
    holes for a pin header - or more likely, two wires.
    I do think I should just give up on the 1950A form factor, which would
    make all these ga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
    [DaisySeed.kicad_pcb, DaisySeed.kicad_sch, electrosmith.kicad_sch]
2025-09-08 Fix pcb layerselection on Daisy Seed board
    I have no idea what happened, but I think this got corrupted as part of
    the KiCad 9.0 downgrade. Or me just fat-finger things randomly.
    Regardless, this really confused me when generating some rather invalid
    gerbers. It's hopefully right now.
    [DaisySeed.kicad_pcb]
2025-09-09 Add very incomplete and broken stm32 board
    The potential plan is to maybe try to actually recreate a subset of what
    the Daisy Seed does, and have it populated at jlcpcb.
    Because I'm not excited about hand-soldering the kinds of components
    this will need (although so far I've picked stuff that should be doable,
    so maybe I change my mind and just go for a stencil).
    This is probably all kinds of broken garbage. And it's very incomplete.
    I've done a MCU board before, but that was years ago. I've never done
    one of the stm32 ones.
    Not yet done: SWD, proper USB, and the PCM3060. And whatever else I'm
    missing and haven't even thought of yet.
    Also, since I've picked a stm32 part that I could m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
    [MCU.kicad_sch, Power.kicad_sch, STM32.kicad_pcb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]
2025-09-09 Add aggressive low-pass filter to the Daisy Seed base board output
    This is from me looking at the HF noise from the Daisy Seed on the
    oscilloscope, and then checking what the Hothouse padal looks like.
    The Hothouse actually looks really clean - kudos to Ricky Sheaves. The
    reason seems to be a rather aggressive low-pass filter with the 3dB
    point at 22kHz. That will attenuate some of the audio band too, but
    looks like it's the right thing to do considering the noise.
    (Of course, the Hothouse also does an op-amp to buffer the end result.
    My silly discrete component board does not. That will affect the end
    result too, but the output impedance should already be pretty low for a
    guitar pedal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
    [DaisySeed.kicad_pcb, DaisySeed.kicad_sch, sim.kicad_sch]
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
